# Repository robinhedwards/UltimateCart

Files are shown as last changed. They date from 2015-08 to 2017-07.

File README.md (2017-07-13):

Ultimate Cart
=============
The Ultimate Cart is an SD-card based multicart for the Atari 8-bit, which I've been developing for the last few months.
It allows you to browse the SD card on the atari and launch cartridge images from ROM and CAR files from the menu.
The PCB is designed to fit in a standard grey cartridge case (after a bit of modification with some clippers and a file).

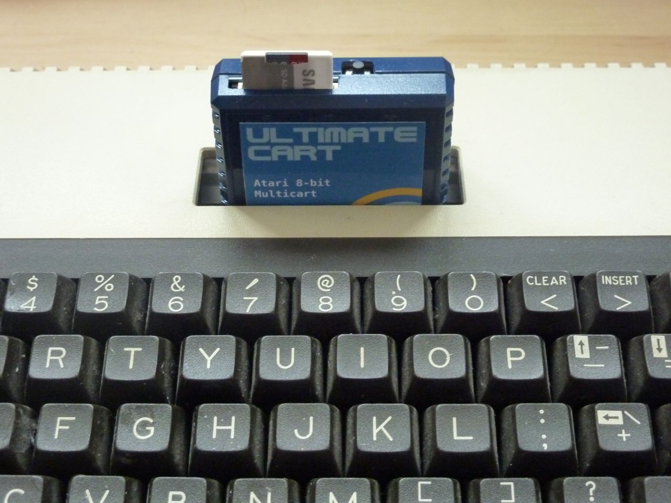
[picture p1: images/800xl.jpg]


It supports most ROMs up to 1 megabyte in size, including standard 8k and 16k cartridges, XEGS, AtariMax 1 & 8mbit ROMs,
SIC! Cart, Bounty Bob, OSS, SDX & Williams. ROM dumps can be easily converted into CAR format with my html/javascript
conversion utility, [RomToCar](http://htmlpreview.github.com/?https://github.com/robinhedwards/UltimateCart/master/RomToCar.html).

Update (Feb-2016)
-----------------
New firmware also allows XEX files (Atari executables) to be launched direct from the SD card.

PCB Images
----------
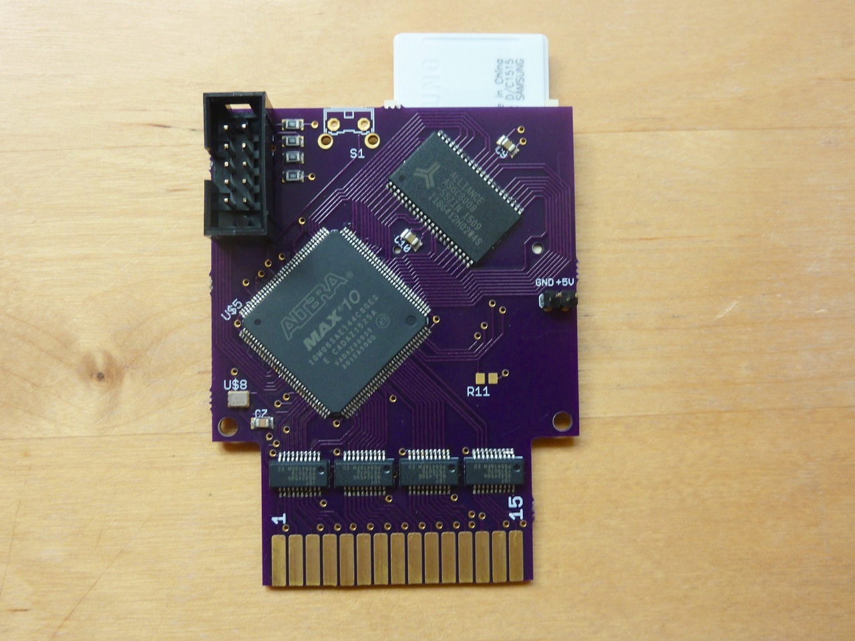
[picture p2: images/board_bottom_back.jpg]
Bottom/Back of PCB when inserted in Atari

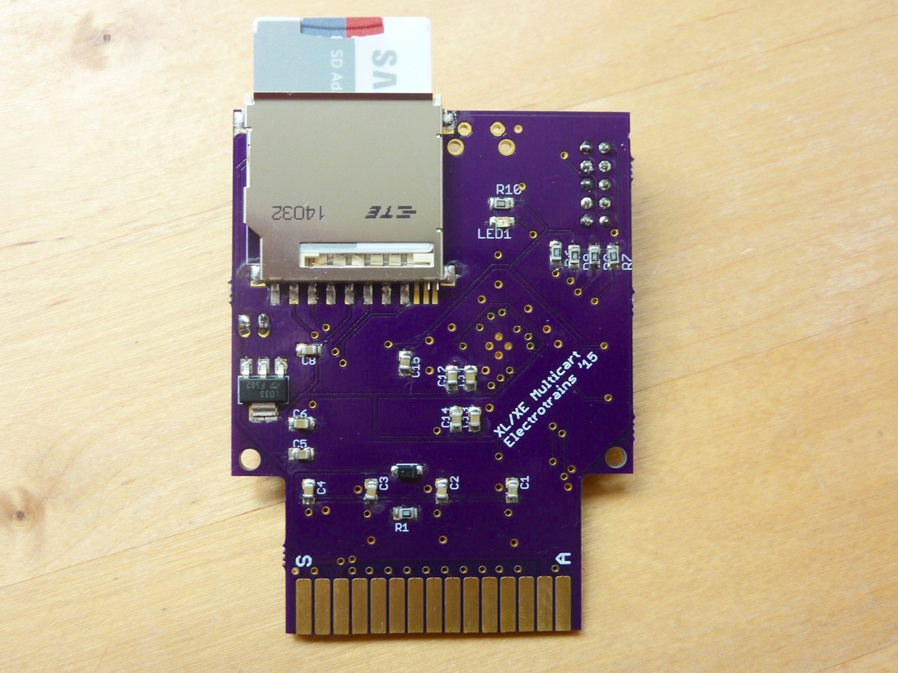
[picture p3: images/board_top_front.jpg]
Top/Front of PCB when inserted in Atari


Bill of Materials
-----------------

The FPGA originally used was an engineering sample (ES) variant of the chip. The production version of the FPGA is now available
and can be used instead. The programming files for the ES seem to work fine on the production chip.

```
1 x PCB (eagle .brd file can be uploaded to e.g. OSH park)
1 x Altera 10M08SAE144C8G or ES variant (Mouser part #989-10M08SAE144C8G/ES)
1 x Alliance Memory AS6C8008-55ZIN (Mouser part #913-AS6C8008-55ZIN)
4 x IDT QS3245QG (Mouser part #972-QS3245QG)
1 x 1N4148 Diode SOD-123 (e.g. RS Stock # 700-3671)
1 x Abracon ASE-50.000MHZ-ET (Farnell order code #2467898)
1 x LD1117S33TR (Farnell order code #1202826)
1 x TE Connectivity 2041021-3 or -4 (Farnell order code #2112526, Mouser part #571-2041021-1)
1 x Shrouded box header 2x5 (e.g. Hobbytronics.co.uk - BOXHEAD25, Farnell order code #2215304)
1 x Momentary tactile switch Right Angled PCB Mount (ebay)
3 x 10uF 0805 Capacitors (e.g. Farnell order code #2320856)
11 x 0.1uF 0805 Capacitors (e.g. Farnell order code #1759143)
1 x 0.01uF 0805 Capacitor (e.g. Farnell order code #1759246)
9 x 10k 0805 Resistor (e.g. Farnell order code #2447553)
1 x 0805 LED (e.g. Farnell order code #1581239)
1 x 200ohm 0805 Resistor (e.g. Farnell order code #2447602)
1 x Header male 2x1 0.1" pitch
1 x 47k 0805 Resistor (e.g. Farnell order code #2447664) [v3 Board only]
```

Assembly
--------

Although the schematic, board file and assembled images above are probably sufficient by themselves
for a determined person to complete the board, here is the method I'm using to assemble the boards.

You will need:
```
Solder paste (I used standard chipquik unleaded) syringe
Some way of reflowing the board (e.g. cheap toaster oven)
Solder paste stencil for the fpga side (optional, but recommended - see below)
Tweezers (or a better tool) for placing the components
Soldering iron
Flux and braid to fix any bridged pins (you may not need if you use a stencil)
USB Blaster to program the fpga
Blu-tac I find useful for keeping things steady
```

You can either apply solder paste by hand (using a syringe) or using a stencil. Having done it both ways,
I'd say the ten pounds I spent on a stencil was the best money I've ever spent! You can get a stencil made
cheaply from a variety of places. I'd recommend either oshstencils (USA) or smtstencil.co.uk (UK). The
paste layer was not correct on the original board, but was corrected in the revised version.

Apply the solder paste to the fpga side of the board, making sure you don't forget the ground pad. The
revised board removes R11 (a pullup resistor on the SD card line) which is not required (since SD cards
have an internal pull-up on CS).

Then populate the components, with reference to the marks on the board and the images above.
Bake the board in an over until the paste melts (you'll see it shine), leave it for about 30s-1min, then open
the oven door and let it cool.

Apply solder paste to the other side of the board (leaving the SD card which is hand soldered). There is
less need for a stencil for this side of the board, a syringe is fine. Populate (make sure you get the polarity
of the LED and diode correct) and bake again.

Before you do any hand soldering, check for bridged pins on the ICs. Some pins are bridged on the PCB - thats ok.
Any others, use braid, flux and soldering iron to remove.

Next you will need to hand solder the jtag box header (slot facing outwards), and 2x1 male header.

Now is a good time to check for shorts - (1) between the +5V and GND pins of the male header, (2) between +3.3v
and GND on the regulator, and (3) between VCC and GND on the IDT quickswitches. If you find a short then STOP
and fix it. There will be a bridge somewhere. Refer to the eagle files to help identify the location.

Once that's done, you should be able to power up the board, plug in a USB blaster and program the chip from
Quartus (use the pof file - this permanently programs the chip). If successful you should see the LED on the
board blinking.

Finally, hand solder the SD card slot and reset button to the board. You're done!

Erratum (20-Oct-15)
-------
Someone who has built this project got in touch to report that some SD cards fail to be recognised.
It appears that a 10k-100k pullup is required on the SD card DO (pin 7), or some cards will fail to initialise.
I haven't come across this in the 10 different SD cards I've tested, but if you do have problems then you can fix
it by adding a 47k pull-up resistor as shown in the photo below.

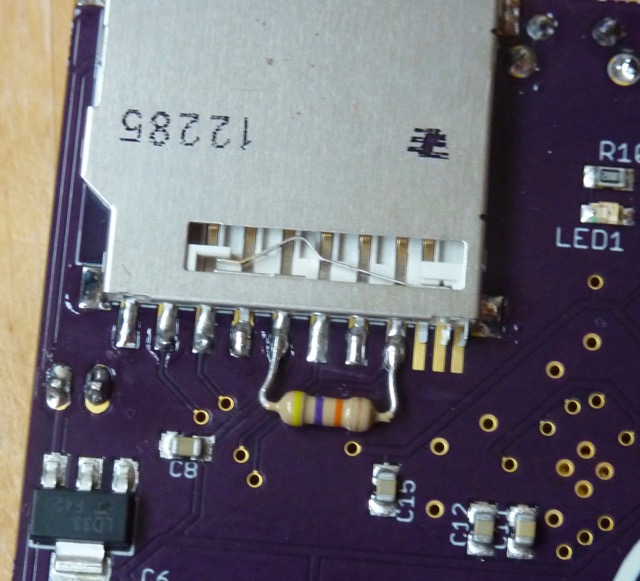
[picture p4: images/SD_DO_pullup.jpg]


Note (1-Mar-16) - I have now uploaded a revised version of the board (v3) which adds this resistor to the PCB (labelled R11).

3d Printed Cartridge Shell (13-Jul-17)
-------
I have added STL files (and the source files) so you can use a 3d printer to make a nice cartridge shell for your PCB.
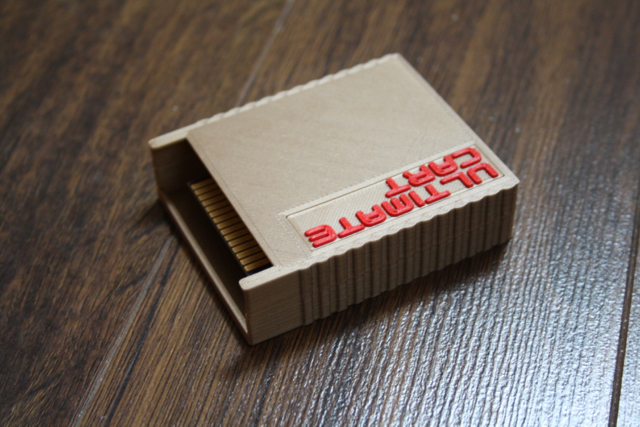
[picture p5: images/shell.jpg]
3d printed shell

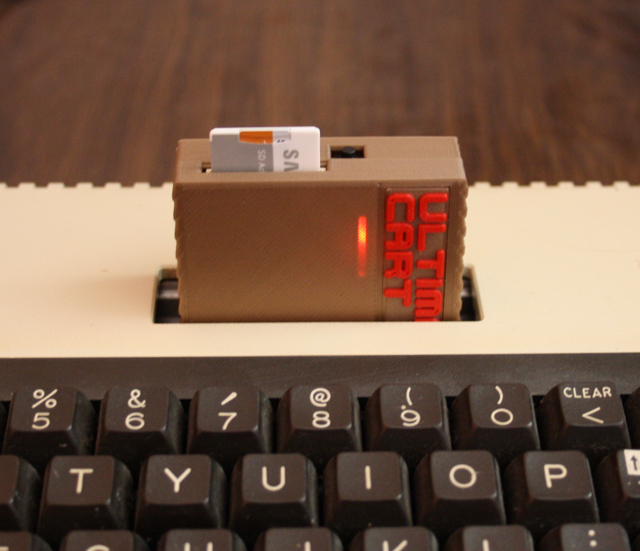
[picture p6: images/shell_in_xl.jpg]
3d printed shell when inserted in Atari


Credits
-------
* Design, PCB & FPGA firmware by Robin Edwards (electrotrains at atariage)
* Atari boot menu & XEX loader by Jonathan Halliday (flashjazzcat at atariage)
* Debugging - Matthias Reichl (HiassofT at atariage)
* Help, suggestions and FAT32 LFN code from Mark Watson (foft at atariage)

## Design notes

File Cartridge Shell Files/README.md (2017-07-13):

STL files for 3d printing a shell for the Ultimate Cart.
(License Creative Commons Attribution Share Alike 4.0)

Notes

The overall shape and dimensions were matched to an XL-era Atari Cartridge.

I sliced with Cura and printed on a Wanhao Duplicator i3 v2.1

Front and back are optimised for printing with a 0.3mm layer height.
The front requires support (i.e. scaffolding) under the reccess for the logo insert.

The logo was designed for a 0.2mm layer height, with a filament change after the third layer.

The OpenSCAD source files are supplied, should you want to tweak the design. Its probably not a good example of how to use OpenSCAD - this was my first attempt to use the software.

Requires 2 x M3 14mm screw (or slightly longer)

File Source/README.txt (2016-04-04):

The Quartus project needs Quartus II 15.1 or above.

Some notes
==========
You should be able to just compile to product a valid sof file.
To generate a pof from the sof file, select File/Convert Programming Files, then Mode: Internal Configuration.

The nios cpu build files are in the host directory, but can be regenerated from the host.qsys project.

The boot_rom.hex file can be updated with a new Atari 8k boot ROM file (see Source/AtariBootROM).
Do Processing/Update Memory Initialization File then Re-assemble after doing this.

To change the fpga Nios firmware, use Nios II software build tools for Eclipse. Both sdcard and sdcard_bsp projects need to be added to the workspace.
Make Targets/Build/mem_init_generate will generate the firmware hex file.
Then do Processing/Update Memory Initialization File and Re-assemble after doing this.

You can also debug the firmware in Eclipse with using the JTAG UART. Run as/Nios II Hardware and the console will display debug output.

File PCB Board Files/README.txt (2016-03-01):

Eagle files for the PCB.

v2 removes an un-needed pull-up resistor on the SD card CS line.
It also includes fixes to the paste layer so you can order a stencil from the board file.
Finally, it adds a funky logo to the top of the board to match the label.

v3 adds a 47k pull-up resistor (marked R11) to SD card as discussed in the erratum on the main page. R11 is on the SD card side of the board, near the SD card slot itself.

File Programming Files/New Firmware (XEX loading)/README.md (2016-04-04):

The new Firmware with XEX loading and better boot menu written by Jonathan Halliday (adds joystick control).

The programming files were generated from Quartus 15.1. Use the variant that matches the chip on your board.

The source code is for this firmware.

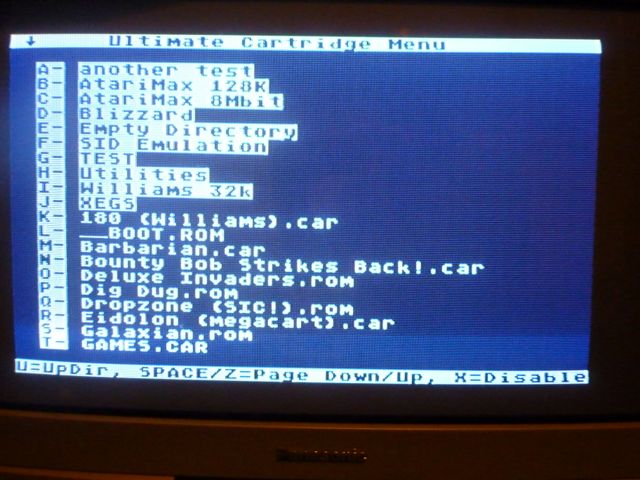
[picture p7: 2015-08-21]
images/menu.jpg

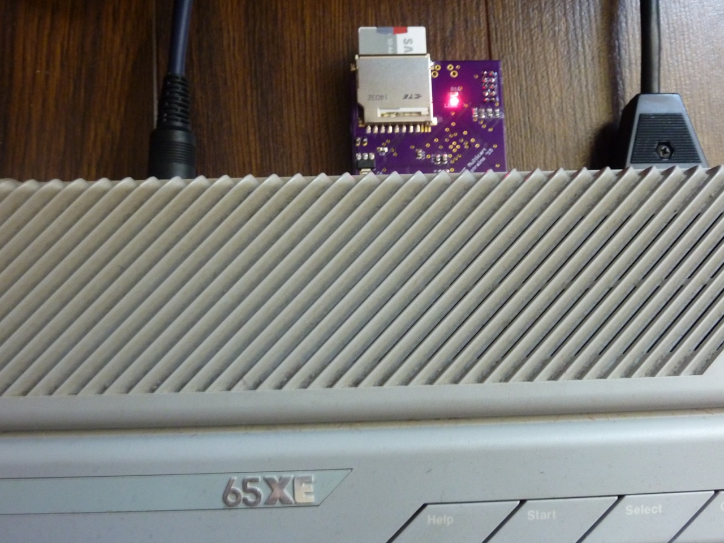
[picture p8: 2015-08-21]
images/uncased_65xe.jpg

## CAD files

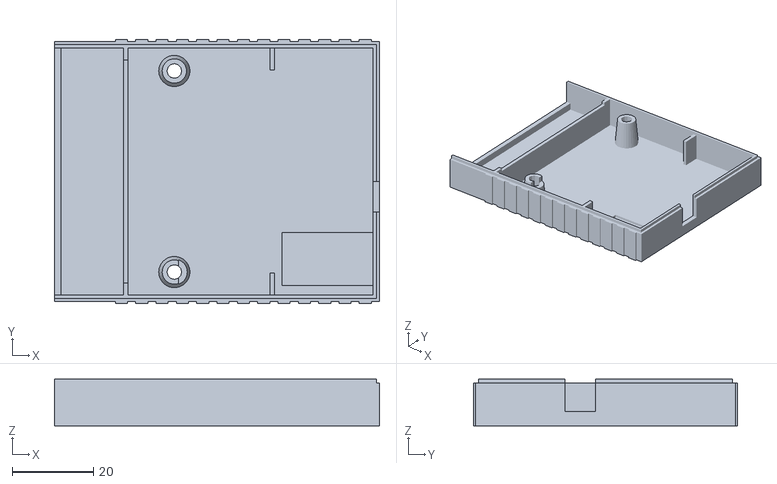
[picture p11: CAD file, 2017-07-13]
Cartridge Shell Files/ultimate_back.stl
80.0 x 65.0 x 11.5

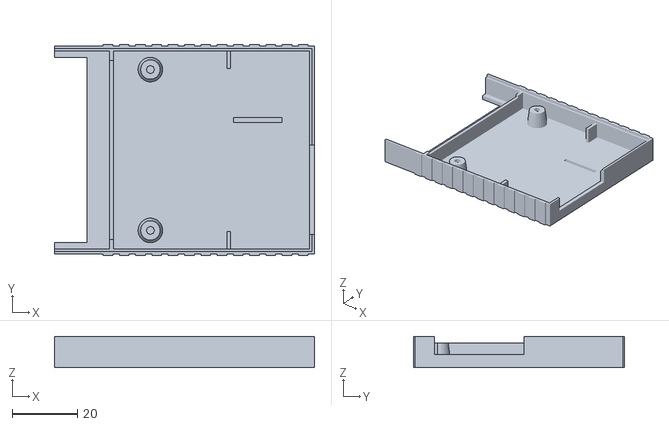
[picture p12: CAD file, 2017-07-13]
Cartridge Shell Files/ultimate_front.stl
80.0 x 65.0 x 9.60

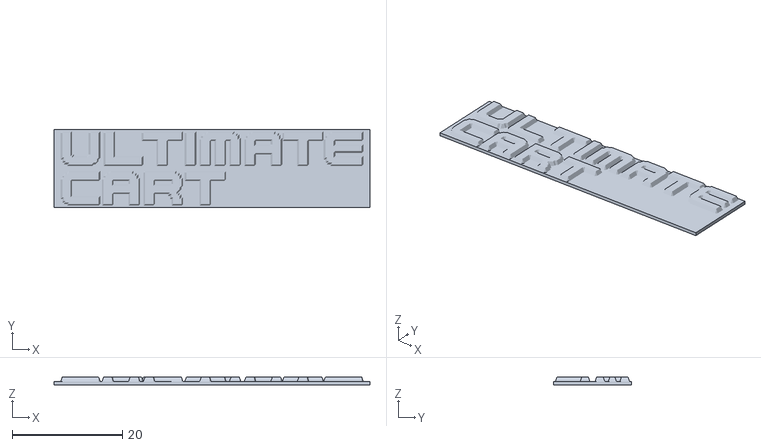
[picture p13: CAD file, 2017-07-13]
Cartridge Shell Files/ultimate_logo.stl
57.3 x 14.1 x 1.40

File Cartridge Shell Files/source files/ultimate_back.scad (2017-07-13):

/* Ultimate Cart shell
   (c) R.Edwards 2017
*/

ridge_width = 0.5;
cart_length=80;
cart_width=65 - (ridge_width*2);
cart_height=11.5;
screw_sep = 49.5;
front_thickness = 1.6;
sides_thickness = 1.6 - 0.05;
support_thickness = 1.2 - 0.05;
support_height = 10.5;
rim_height=1;

difference() {
    union() {
        difference() {
            // main shell
            union() {
                cube([cart_length, cart_width, cart_height-rim_height]);
                // rim
                translate([0, sides_thickness/2, cart_height-rim_height])
                    cube([cart_length-sides_thickness/2, sides_thickness/2, rim_height]);
                translate([0, cart_width-sides_thickness, cart_height-rim_height])
                    cube([cart_length-sides_thickness/2, sides_thickness/2, rim_height]);
                translate([cart_length-sides_thickness, sides_thickness/2, cart_height-rim_height])
                    cube([sides_thickness/2, cart_width-sides_thickness, rim_height]);
            }
            // make hollow
            translate([0, sides_thickness, front_thickness])
                cube([cart_length-sides_thickness,
                    cart_width-sides_thickness*2,
                    cart_height-front_thickness]);
            // cutout reset button slot
            translate([cart_length-sides_thickness, 22, cart_height-8])
                cube([sides_thickness, 7.5, 8]);
            // cutout programming header
            translate([56, 4, front_thickness/2])
                cube([22.5, 13, front_thickness]);
        }    
        // end
        cube([sides_thickness, cart_width, 4]);
        // pcb supports
        difference() {
            translate([17, sides_thickness, 0])
                cube([support_thickness, cart_width-sides_thickness*2, cart_height]);
            translate([17, (cart_width-55)/2, support_height])
                cube([support_thickness, 55, cart_height-support_height]);
        }
        translate([53, 0, 0])
            cube([support_thickness, 7, support_height]);
        translate([53, cart_width-7, 0])
            cube([support_thickness, 7, support_height]);
        // screw holes
        difference() {
            translate([29.5, (cart_width-screw_sep)/2, 0])
                difference() {
                    cylinder(h = support_height, r1 = 4, r2 = 3,  $fs = 1);
                    cylinder(h = support_height, r1 = 1.8, r2 = 1.8,  $fs = 1);
                }
            translate([29.5+1, (cart_width-screw_sep)/2-5, support_height-2])
                cube([10, 10, 2]);
        }
        translate([29.5, cart_width-(cart_width-screw_sep)/2, 0])
            difference() {
                cylinder(h = support_height, r1 = 4, r2 = 3,  $fs = 1);
                cylinder(h = support_height, r1 = 1.8, r2 = 1.8,  $fs = 1);
            }
        // ridges
        for (i = [15: 5: cart_length-5])
            union() {
                translate([i, -ridge_width, 0])
                    cube([3, ridge_width, cart_height-rim_height]);
                translate([i, cart_width, 0])
                    cube([3, ridge_width, cart_height-rim_height]);
            }
    }
    // screw head
    translate([29.5, (cart_width-screw_sep)/2, 0])
        cylinder(h = 0.6, r1 = 3.5, r2 = 3.5,  $fs = 1);
    translate([29.5, (cart_width-screw_sep)/2, 0.6])
        cylinder(h = front_thickness-0.6, r1 = 3.5, r2 = 1.8,  $fs = 1);

    translate([29.5, cart_width-(cart_width-screw_sep)/2, 0])
        cylinder(h = 0.6, r1 = 3.5, r2 = 3.5,  $fs = 1);
    translate([29.5, cart_width-(cart_width-screw_sep)/2, 0.6])
        cylinder(h = front_thickness-0.6, r1 = 3.5, r2 = 1.8,  $fs = 1);
}

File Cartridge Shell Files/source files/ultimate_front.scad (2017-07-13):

/* Ultimate Cart shell
   (c) R.Edwards 2017
*/

ridge_width = 0.5;
cart_length=80;
cart_width=65 - (ridge_width*2);
cart_height=9.6;
screw_sep = 49.5;
front_thickness = 1.6;
sides_thickness = 1.6 - 0.05;
support_thickness = 1.2 - 0.05;
support_height = 7.6;
rim_height = 1;
logo_width = 14.5;
logo_height = 58;

difference() {
    union() {
        difference() {
            // main shell
            cube([cart_length, cart_width, cart_height]);
            // rims
            translate([0, sides_thickness/2, cart_height-rim_height])
                cube([cart_length-sides_thickness/2,
                    cart_width-sides_thickness, rim_height]);
            // make hollow
            translate([0, sides_thickness, front_thickness])
                cube([cart_length-sides_thickness,
                    cart_width-sides_thickness*2,
                    cart_height-front_thickness]);
            // cutout sd card slot
            translate([cart_length-sides_thickness, 6, cart_height-5.5])
                cube([sides_thickness, 27.5, 5.5]);
            // cutout cart port
            translate([0, (cart_width-57)/2, 0])
                cube([10, 57, cart_height]);
            // cutout led shine through
            translate([55, 40.5, 0.3])
                cube([15, 1.5, front_thickness-0.3]);
        }    
        // pcb supports
        difference() {
            translate([17, 0, 0])
                cube([support_thickness, cart_width, cart_height-rim_height]);
            translate([17, (cart_width-55)/2, support_height])
                cube([support_thickness, 55, cart_height-support_height]);
        }
        translate([53, 0, 0])
            cube([support_thickness, 7, support_height]);
        translate([53, cart_width-7, 0])
            cube([support_thickness, 7, support_height]);
        // screw holes
        translate([29.5, (cart_width-screw_sep)/2, 0])
            difference() {
                cylinder(h = support_height, r1 = 4, r2 = 3,  $fs = 1);
                cylinder(h = support_height, r1 = 1.25, r2 = 1.25,  $fs = 1);
            }
        translate([29.5, cart_width-(cart_width-screw_sep)/2, 0])
            difference() {
                cylinder(h = support_height, r1 = 4, r2 = 3,  $fs = 1);
                cylinder(h = support_height, r1 = 1.25, r2 = 1.25,  $fs = 1);
            }
        // ridges
        for (i = [15: 5: cart_length-5])
            union() {
                translate([i, -ridge_width, 0])
                    cube([3, ridge_width, cart_height]);
                translate([i, cart_width, 0])
                    cube([3, ridge_width, cart_height]);
            }
    }
    // logo space
    translate([cart_length-logo_height-2, cart_width-logo_width-3.5, 0])
        cube([logo_height, logo_width, 1]);
}

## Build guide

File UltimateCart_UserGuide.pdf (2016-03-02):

## Ultimate Cartridge for Atari 8-bit Computers

### Website

The Ultimate Cart is a multi-cart for Atari 400/800/XL/XE computers. It is open-source hardware and software. The project website is: https://github.com/robinhedwards/UltimateCart

### Basic Usage

The Ultimate Cartridge can be used uncased in an XE system.

Mounting inside a cartridge case is recommended for XL computers since the flaps on the slot may damage the bare PCB.

The SD card slot side should be facing upward (or forwards) in the computer, with the chip side downwards (or backwards).

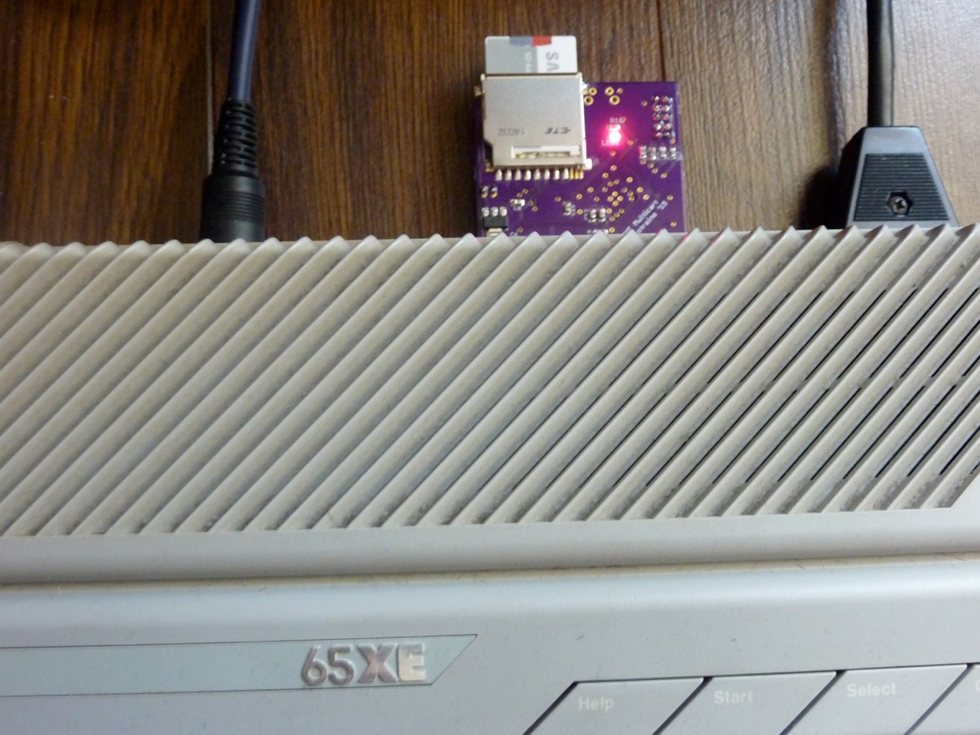
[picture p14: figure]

Insert an SD card (either full size, or MicroSD in an adapter) into the slot. The card does not require any special preparation, since the Ultimate cartridge can read FAT (including FAT32) file systems. Long file names are supported.

When the Atari is powered on, a list of any ROM & CAR files and directories on the SD card should be shown on the Atari’s screen. Keyboard commands are shown at the bottom of the screen. A newer version of the firmware also supports XEX files – this may be installed on your cartridge.

It is best to organize your files in directories since the cartridge will load and sort the files in the directory before display. If you have to many files in any one directory, this may cause a noticeable pause before display.

You can disable the cartridge (using the X key) if you want to boot normally (e.g. to disk) and leave the cartridge plugged in (to avoid wear and tear).

### SD Cards

Higher speed SD cards are recommended. SDHC (High capacity) cards are supported. On a high-speed card, a 1 megabyte ROM file (e.g. AtariMax) takes about 3 seconds to be loaded into the cartridge when selected. Slower cards may take longer.

### Status LED

LED | Meaning
Blinking | The cartridge menu screen is active
On | Selected cartridge is enabled for access (RD4 or RD5 active)
Off | Selected cartridge is disabled (RD4 and RD5 inactive)

### Reset Button

Press the reset button (next to the SD card slot) to reset the cartridge firmware. This will generally cause the Atari to crash, and the reset button on the Atari can then be pressed to return to the cartridge menu.

### Supported Cartridge Types (CAR files)

Description | CAR Type(s)
Standard Atari 8k | 1
Standard Atari 16k | 2
Atari XEGS 32-1024k | 12-14, 23-25
AtariMax 1mbit (128k) | 41
AtariMax 8mbit (1024k) | 42
Switchable XEGS 32-1024k | 33-38
Megacart 16-1024k | 26-32
Bounty Bob | 18
Williams 32k, 64k | 8, 22
OSS 8k | 44
OSS 16k (034M) | 3
OSS 16k (043M) | 45
OSS 16k (type B) | 15
SIC!Cart (128k, 256k, 512k) | 54-56
SDX 64k | 11
Diamond 64k | 10
Express 64k | 9
SDX 128k | 43
Blizzard 16k | 40

### Converting to CAR format

Utilities are available to convert ROM/BIN files into the CAR file format. The ROM2CAR utility available on the project website provides an easy drag and drop interface to do this.

With the most common 8k and 16k Atari ROMs, there is no need to convert these first to CAR format since these cartridge types will simply be assumed from the size of the ROM file (see below).

### ROM Files

Plain ROM files are supported, but since these files are raw cartridge dumps, the Ultimate Cart will decide what type of cartridge they come from based on the file size only. The table below shows what types will be used.

ROM File Size | Cartridge Type
8k | Standard Atari 8k
16k | Standard Atari 16k
32k | Atari XEGS 32k
64k | Atari XEGS 64k
128k | Atari XEGS 128k
256k | SIC!Cart
512k | SIC!Cart
1024k | AtariMax 8mbit

### XEX Files

The latest version of the firmware adds a new menu, with joystick control. It also supports loading XEX files (in addition to cartridge files). Note that the XEX loader is copied to location $700 in the Atari’s RAM. This should be compatible with most software in XEX form.

### Problem Files

You may come across files with a .BIN extension. These are often just .ROM files and can be renamed.

You may also find ROM files where the Ultimate Cart menu gives the error “Bad ROM/CAR file”. This happens when the ROM file is not an exact multiple of 1,024 bytes. In this case, the ROM dump may have already been converted to a CAR file (with a 16 byte header) but has been wrongly named. In this case you can simply rename the file from .ROM to .CAR.

### Alternative Menu

If a file named _BOOT.ROM (8k) is present in the root directory of the SD card, the cartridge will attempt to overwrite the in-built boot ROM with this file before the Atari starts accessing the ROM. This allows the menu to be replaced with an alternative version, but successful operation may require a fast SD card. Delete the file to revert to the built-in menu.

Source code for the built-in menu is available on the project website.

Note that setting the hidden or system flag on _BOOT.ROM (using a PC) will prevent this file being displayed on the menu.

### Cartridge Cases

The Ultimate Cart PCB is designed to fit in a modified Atari grey (XL-era) cartridge shell. You will need a heavy-duty file and some clippers (e.g. wire clippers). This is only intended to be a rough guide.

First separate the two sides of the shell, trying not to break any of the tabs that hold the two parts of the shell together. Remove the original PCB and any glue blobs.

From the front (i.e. facing forwards when inserted) part of the shell you will need to remove the plastic centre “post” at its base, since there is no hole in the Ultimate Cart PCB. You will also need to remove the central “clip” at the top of the front shell.

You should then be able to roughly place the Ultimate Cart PCB (chip side up) in the top of the shell (like the PCB you removed). It won’t sit correctly (yet).

At this point it will be clear that you will need to remove 2-3mm height of the side extensions on the top and (partially on the) bottom shell. It should also be clear where slots need to be filed in the front and back of the shell to accommodate the SD card and button.

### Upgrading the Firmware

Should new firmware be available, a USB Blaster (or clone) can be used to upgrade your cartridge. A JTAG socket is present on the FPGA side of the board. Connect this to the USB Blaster and power the board. A POF file can then be programmed to the chip using the Altera Quartus Programmer (free download).

To power the board, either supply 5V using the two pin header provided. Alternatively, the board can be powered during the firmware update through the cartridge slot of the Atari.

### Board Assembly Information

If you purchased an assembled cartridge from the author, the cartridge has been assembled one of two ways:

Boards purchased before Sept 2015

Assembled using two types of lead-free solder paste. The lower side (with two large chips) uses Sn42Bi58 paste (melting point 130 degrees C). The upper side (with the SD card slot) uses Sn96.5Ag3Cu0.5 paste (melting point 230 degrees), with the exception of the SD card slot itself, which has been soldered with Sn42Bi58. In case of repair, avoid leaded solder since it will lead to brittle and poor joints if mixed with Sn42Bi58.

Boards purchased on or after Sept 2015

Assembled using SN96.5Ag3Cu0.5 paste on both sides (melting point 230 degrees).

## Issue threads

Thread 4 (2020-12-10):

Memory Short

Kalidomra, 2020-12-10:
I have tried to build this twice. Each time there seems to be a dead short to the memory after programming. Everything is fine, I program the chip and the memory chips gets too hot to touch. What am I doing wrong?

pazuzu72, 2020-12-20:
> I have tried to build this twice. Each time there seems to be a dead short to the memory after programming. Everything is fine, I program the chip and the memory chips gets too hot to touch. What am I doing wrong?

Can you post a photo o pcb populated?

Kalidomra, 2020-12-20:
Sure, here it is.
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

pazuzu72, 2020-12-21:
The photo is not very clear. Are you sure there is no solder bridge?

Kalidomra, 2020-12-29:
Here is what I have done:

1st attempt:
- Soldered all of the parts, inspected for solder bridges. Powered the board, no issues. Minimal power draw.
- Programmed the Altera.
- After programming, upon power up the board was drawing too much power and memory was hot to the touch.
- Powered down.
- Removed the memory, installed on a blank board.
- Powered the new blank board, memory was still drawing too much power and getting hot.
- Reinspected the original board via microscope, no solder bridges.
- Ordered new memory chip, installed, same result.
- Gave up

2nd attempt:
- Ordered all new parts.
- Install everything except U1-4, SD card socket and switch.
- Triple checked every connection.
- Same result as first attempt.

pazuzu72, 2020-12-29:
I have no idea !! I've done more than 130, this has never happened to me. I program them directly powered by an atari computer, not via the external 2 pin header. Nothing else comes to mind.

jhusak, 2020-12-30:
I think the issue may be in unstable inputs when no level shifters installed. I would solder them in and then test.
This is non-standard behavior when mounting only some parts, not all, as other people.

Kalidomra, 2020-12-30:
In my first attempt I had all of the components installed proper to programming.  There may be an issue with the gerber files I generated. Would it be possible to post the gerbers for the successful builds?

pazuzu72, 2020-12-31:
[Ulimate_2020-12-31.zip](https://github.com/robinhedwards/UltimateCart/files/5757515/Ulimate_2020-12-31.zip)
Sure!

pazuzu72, 2020-12-31:
[Ultimate_Cart_gerber.zip](https://github.com/robinhedwards/UltimateCart/files/5757521/Ultimate_Cart_gerber.zip)
Sure!

Kalidomra, 2020-12-31:
Is it possible that powering the board without being hooked to the logic and pull up or pull downs for the Atari is causing the Altera to get in a state that drives the WE High and also tries to drive the Data pins?

mulcmu, 2021-01-01:
I built 3 and programmed them using the external +5V power input headers without being installed in an Atari.

pazuzu72, 2021-01-01:
> Is it possible that powering the board without being hooked to the logic and pull up or pull downs of the Atari is causing the Altera to get in a state that drives the WE High and also tries to drive the Data pins?

I don't think that's the problem!

Kalidomra, 2021-01-02:
I have been doing a little troubleshooting today. I  setup the scope on the 5v rail and noticed a 13v spike for 6ms on switching on the power supply. Would that be enough to fry the sram? I have also checked the entire board, there are no shorts, it all connected correctly.

jhusak, 2021-01-03:
Well, I would throw away such a "stabilized" power supply. Yes, it would kill your chips. 6 ms is a long time.

Kalidomra, 2021-01-03:
Yup, cheap POS. New one on order. I will also get some new  SRAM and try again. I'm sure that was the issue. Thanks for all the help.

pazuzu72, 2021-01-03:
You can power it inserted in atari cartridge port for programming!!! I always do in that way.

Closed 2021-01-21.

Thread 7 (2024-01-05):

gerber files?

vwbug2007, 2024-01-05:
where's the Gerber files? those are not compatible with jlcpcb website

vwbug2007, 2024-01-05:
also kicad export to gerber fails drc

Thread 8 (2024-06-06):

Bug in the SIC! cart support

woj76, 2024-06-06:
It seems that both "left" and "right" SIC! cart banks are always switched on regardless of the control register configuration resulting in the whole $8000-$BFFF memory range always being mapped when the cart is active. At least this is the best diagnosis I can do without the emulator, and this behaviour breaks my particular SIC! image cart that I developed. The same cart image works fine everywhere else (AVG, SIDE3, Altirra).

woj76, 2025-01-10:
I investigated this a bit more, and so far I can conclude that the problem I saw is **not** related to the SIC! banking mechanism implementation in UC, so my first claim does not hold. So even though I do get some weird behavior suggesting some problems with device memory mapping on my Atari, it is related to something else (someone suggested cart RAM issues / bad soldering).

robinhedwards, 2025-01-10:
thanks for the update. Closing this issue for now.

woj76, 2025-03-20:
I would like to re-open this, I finally identified the problem, it is in the VHDL, I fixed it a local copy and tested. The issue is that SIC! carts are by default initialized to low bank off and high bank on, UC initialized both banks to on. The line 275 in atari_rom.vhd:

low_bank_enabled <= '1';

should be simply removed.

Closed 2025-01-10.

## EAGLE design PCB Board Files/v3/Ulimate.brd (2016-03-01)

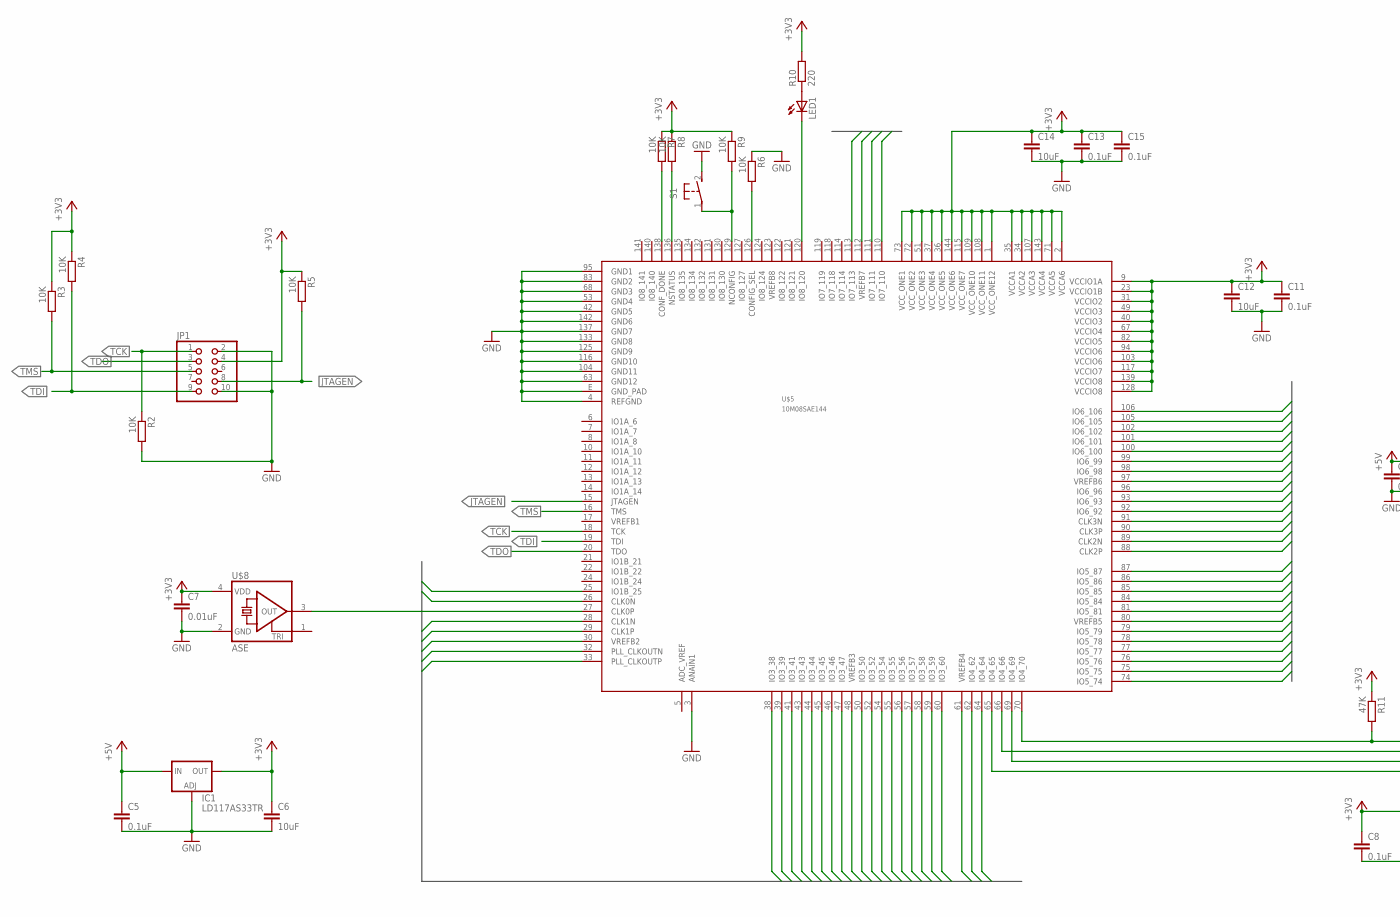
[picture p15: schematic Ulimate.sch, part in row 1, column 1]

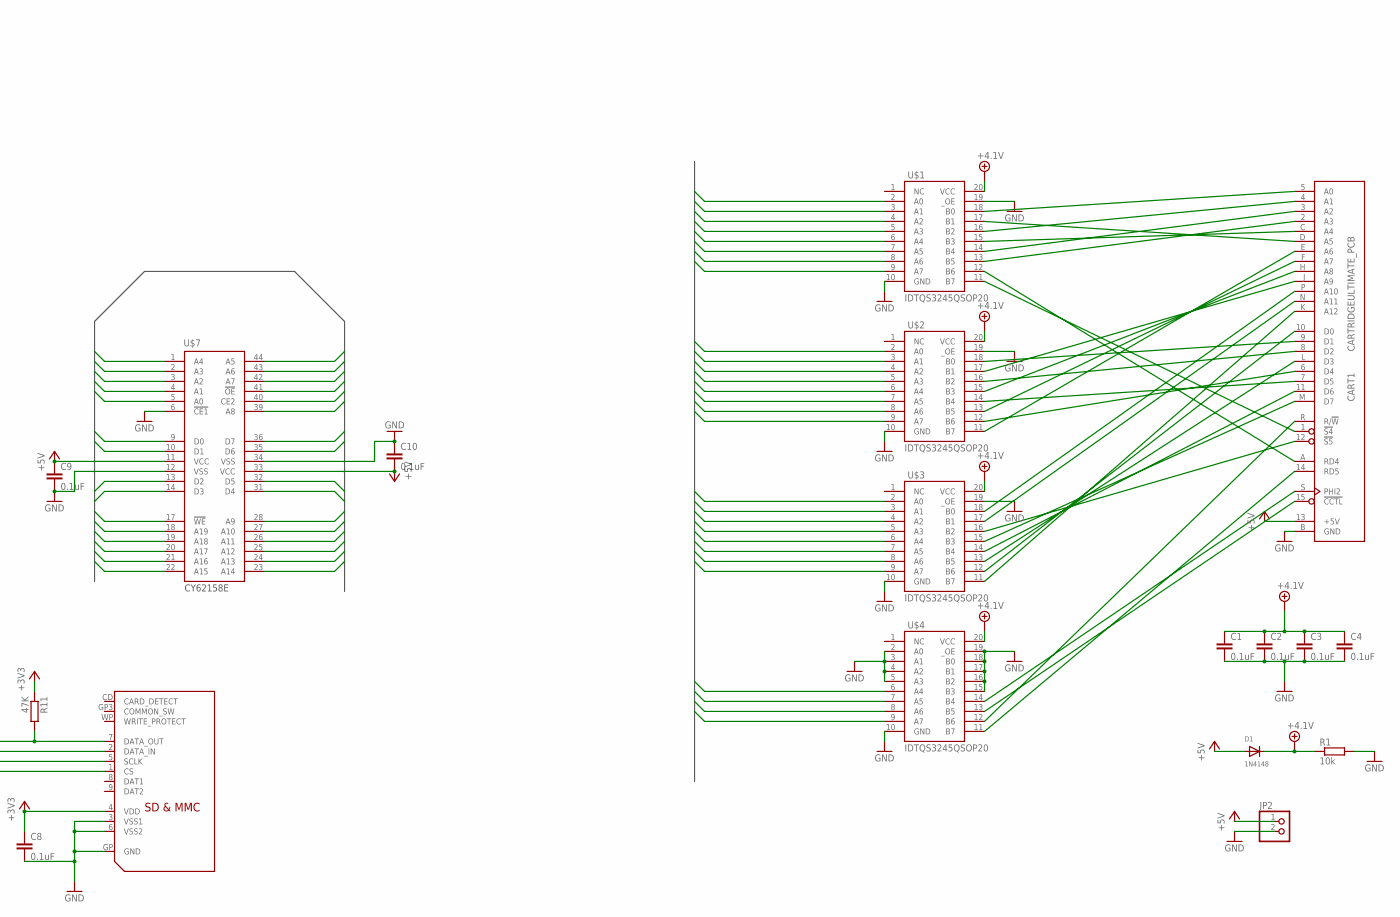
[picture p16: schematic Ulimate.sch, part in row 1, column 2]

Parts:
C1, C2, C3, C4, C5, C8, C9, C10, C11, C13, C15: 0.1uF; C0805K
C6, C12, C14: 10uF; C0805K
C7: 0.01uF; C0805K
CART1: CARTRIDGEULTIMATE_PCB; CART_ULTIMATE
D1: 1N4148; SOD-123FL
IC1: LD117AS33TR; SOT223
JP1: PINHD-2X5; 2X05
JP2: PINHD-1X2; 1X02
LED1: LEDSML0805; SML0805
R1: 10k; R0805
R2, R3, R4, R5, R6, R7, R8, R9: 10K; R0805
R10: 220; R0805
R11: 47K; R0805
S1: 31-XXSKINNY; B3F-31XX-SKINNIER
U$1, U$2, U$3, U$4: IDTQS3245QSOP20; QSOP20
U$5: 10M08SAE144; EQFP144
U$6: SDMMC06132; 06132
U$7: CY62158E; TSOP44-II
U$8: ASE

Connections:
!OE: U$5.106 (IO6_106), U$7.41 (!OE)
!WE: U$5.89 (CLK2N), U$7.17 (!WE)
+3V3: C6.1, C7.1, C8.1, C11.1, C12.1, C13.1, C14.1, C15.1, IC1.4 (OUT), JP1.4, R3.1, R4.1, R5.1, R7.1, R8.1, R9.1, R10.2, R11.1, U$5.1 (VCC_ONE12), U$5.2 (VCCA6), U$5.9 (VCCIO1A), U$5.23 (VCCIO1B), U$5.31 (VCCIO2), U$5.34 (VCCA2), U$5.35 (VCCA1), U$5.36 (VCC_ONE5), U$5.37 (VCC_ONE4), U$5.40 (VCCIO3), U$5.49 (VCCIO3), U$5.51 (VCC_ONE3), U$5.67 (VCCIO4), U$5.71 (VCCA5), U$5.72 (VCC_ONE2), U$5.73 (VCC_ONE1), U$5.82 (VCCIO5), U$5.94 (VCCIO6), U$5.103 (VCCIO6), U$5.107 (VCCA3), U$5.108 (VCC_ONE11), U$5.109 (VCC_ONE10), U$5.115 (VCC_ONE7), U$5.117 (VCCIO7), U$5.128 (VCCIO8), U$5.139 (VCCIO8), U$5.143 (VCCA4), U$5.144 (VCC_ONE6), U$6.4 (VDD), U$8.4 (VDD)
+4.1V: C1.1, C2.1, C3.1, C4.1, D1.C, R1.1, U$1.20 (VCC), U$2.20 (VCC), U$3.20 (VCC), U$4.20 (VCC)
+5V: C5.1, C9.1, C10.2, CART1.13 (+5V), D1.A, IC1.3 (IN), JP2.1, U$7.11 (VCC), U$7.33 (VCC)
A0: U$5.96 (IO6_96), U$7.5 (A0)
A1: U$5.97 (VREFB6), U$7.4 (A1)
A2: U$5.98 (IO6_98), U$7.3 (A2)
A3: U$5.99 (IO6_99), U$7.2 (A3)
A4: U$5.100 (IO6_100), U$7.1 (A4)
A5: U$5.105 (IO6_105), U$7.44 (A5)
A6: U$5.102 (IO6_102), U$7.43 (A6)
A7: U$5.101 (IO6_101), U$7.42 (A7)
A8: U$5.111 (IO7_111), U$7.39 (A8)
A9: U$5.76 (IO5_76), U$7.28 (A9)
A10: U$5.77 (IO5_77), U$7.27 (A10)
A11: U$5.78 (IO5_78), U$7.26 (A11)
A12: U$5.79 (IO5_79), U$7.25 (A12)
A13: U$5.80 (VREFB5), U$7.24 (A13)
A14: U$5.81 (IO5_81), U$7.23 (A14)
A15: U$5.84 (IO5_84), U$7.22 (A15)
A16: U$5.85 (IO5_85), U$7.21 (A16)
A17: U$5.86 (IO5_86), U$7.20 (A17)
A18: U$5.87 (IO5_87), U$7.19 (A18)
A19: U$5.88 (CLK2P), U$7.18 (A19)
CART_A0: U$1.2 (A0), U$5.39 (IO3_39)
CART_A1: U$1.4 (A2), U$5.33 (PLL_CLKOUTP)
CART_A2: U$1.6 (A4), U$5.30 (VREFB2)
CART_A3: U$1.7 (A5), U$5.29 (CLK1P)
CART_A4: U$1.5 (A3), U$5.32 (PLL_CLKOUTN)
CART_A5: U$1.3 (A1), U$5.38 (IO3_38)
CART_A6: U$2.9 (A7), U$5.41 (IO3_41)
CART_A7: U$2.7 (A5), U$5.44 (IO3_44)
CART_A8: U$2.5 (A3), U$5.46 (IO3_46)
CART_A9: U$2.3 (A1), U$5.48 (VREFB3)
CART_A10: U$3.2 (A0), U$5.60 (IO3_60)
CART_A11: U$3.3 (A1), U$5.59 (IO3_59)
CART_A12: U$3.9 (A7), U$5.52 (IO3_52)
CART_CTL: U$4.7 (A5), U$5.64 (IO4_64)
CART_D0: U$3.8 (A6), U$5.54 (IO3_54)
CART_D1: U$2.2 (A0), U$5.50 (IO3_50)
CART_D2: U$2.4 (A2), U$5.47 (IO3_47)
CART_D3: U$3.7 (A5), U$5.55 (IO3_55)
CART_D4: U$2.8 (A6), U$5.43 (IO3_43)
CART_D5: U$2.6 (A4), U$5.45 (IO3_45)
CART_D6: U$3.6 (A4), U$5.56 (IO3_56)
CART_D7: U$3.5 (A3), U$5.57 (IO3_57)
CART_PHI: U$4.6 (A4), U$5.26 (CLK0N)
CART_RD4: U$1.8 (A6), U$5.25 (IO1B_25)
CART_RD5: U$4.9 (A7), U$5.61 (VREFB4)
CART_RW: U$4.8 (A6), U$5.62 (IO4_62)
CART_S4: U$1.9 (A7), U$5.28 (CLK1N)
CART_S5: U$3.4 (A2), U$5.58 (IO3_58)
CE: U$5.110 (IO7_110), U$7.40 (CE2)
D0: U$5.93 (IO6_93), U$7.9 (D0)
D1: U$5.92 (IO6_92), U$7.10 (D1)
D2: U$5.91 (CLK3N), U$7.13 (D2)
D3: U$5.90 (CLK3P), U$7.14 (D3)
D4: U$5.75 (IO5_75), U$7.31 (D4)
D5: U$5.74 (IO5_74), U$7.32 (D5)
D6: U$5.113 (IO7_113), U$7.35 (D6)
D7: U$5.112 (VREFB7), U$7.36 (D7)
GND: C1.2, C2.2, C3.2, C4.2, C5.2, C6.2, C7.2, C8.2, C9.2, C10.1, C11.2, C12.2, C13.2, C14.2, C15.2, CART1.B (GND), IC1.1 (ADJ), JP1.2, JP1.10, JP2.2, R1.2, R2.2, R6.1, S1.2 (S), U$1.10 (GND), U$1.19 (_OE), U$2.10 (GND), U$2.19 (_OE), U$3.10 (GND), U$3.19 (_OE), U$4.2 (A0), U$4.3 (A1), U$4.4 (A2), U$4.5 (A3), U$4.10 (GND), U$4.15 (B3), U$4.16 (B2), U$4.17 (B1), U$4.18 (B0), U$4.19 (_OE), U$5.3 (ANAIN1), U$5.4 (REFGND), U$5.42 (GND5), U$5.53 (GND4), U$5.63 (GND12), U$5.68 (GND3), U$5.83 (GND2), U$5.95 (GND1), U$5.104 (GND11), U$5.116 (GND10), U$5.125 (GND9), U$5.133 (GND8), U$5.137 (GND7), U$5.142 (GND6), U$5.E (GND_PAD), U$6.3 (VSS1), U$6.6 (VSS2), U$6.GP (GND), U$7.6 (!CE1), U$7.12 (VSS), U$7.34 (VSS), U$8.2 (GND)
JTAGEN: JP1.8, R5.2, U$5.15 (JTAGEN)
unnamed: CART1.1 (!S4), U$1.11 (B7)
unnamed: CART1.A (RD4), U$1.12 (B6)
unnamed: CART1.2 (A3), U$1.13 (B5)
unnamed: CART1.3 (A2), U$1.14 (B4)
unnamed: CART1.C (A4), U$1.15 (B3)
unnamed: CART1.4 (A1), U$1.16 (B2)
unnamed: CART1.D (A5), U$1.17 (B1)
unnamed: CART1.5 (A0), U$1.18 (B0)
unnamed: CART1.E (A6), U$2.11 (B7)
unnamed: CART1.6 (D4), U$2.12 (B6)
unnamed: CART1.F (A7), U$2.13 (B5)
unnamed: CART1.7 (D5), U$2.14 (B4)
unnamed: CART1.H (A8), U$2.15 (B3)
unnamed: CART1.8 (D2), U$2.16 (B2)
unnamed: CART1.J (A9), U$2.17 (B1)
unnamed: CART1.9 (D1), U$2.18 (B0)
unnamed: CART1.K (A12), U$3.11 (B7)
unnamed: CART1.10 (D0), U$3.12 (B6)
unnamed: CART1.L (D3), U$3.13 (B5)
unnamed: CART1.11 (D6), U$3.14 (B4)
unnamed: CART1.M (D7), U$3.15 (B3)
unnamed: CART1.12 (!S5), U$3.16 (B2)
unnamed: CART1.N (A11), U$3.17 (B1)
unnamed: CART1.P (A10), U$3.18 (B0)
unnamed: CART1.14 (RD5), U$4.11 (B7)
unnamed: CART1.R (R/!W), U$4.12 (B6)
unnamed: CART1.15 (!CCTL), U$4.13 (B5)
unnamed: CART1.S (PHI2), U$4.14 (B4)
unnamed: U$5.27 (CLK0P), U$8.3 (OUT)
unnamed: R6.2, U$5.126 (CONFIG_SEL)
unnamed: R7.2, U$5.138 (CONF_DONE)
unnamed: R8.2, U$5.136 (NSTATUS)
unnamed: R9.2, S1.1, U$5.129 (NCONFIG)
unnamed: LED1.A, R10.1
unnamed: LED1.C, U$5.120 (IO8_120)
SD_CLK: U$5.69 (IO4_69), U$6.5 (SCLK)
SD_CS: U$5.65 (IO4_65), U$6.1 (CS)
SD_DI: U$5.66 (IO4_66), U$6.2 (DATA_IN)
SD_DO: R11.2, U$5.70 (IO4_70), U$6.7 (DATA_OUT)
TCK: JP1.1, R2.1, U$5.18 (TCK)
TDI: JP1.9, R4.2, U$5.19 (TDI)
TDO: JP1.3, U$5.20 (TDO)
TMS: JP1.5, R3.2, U$5.16 (TMS)

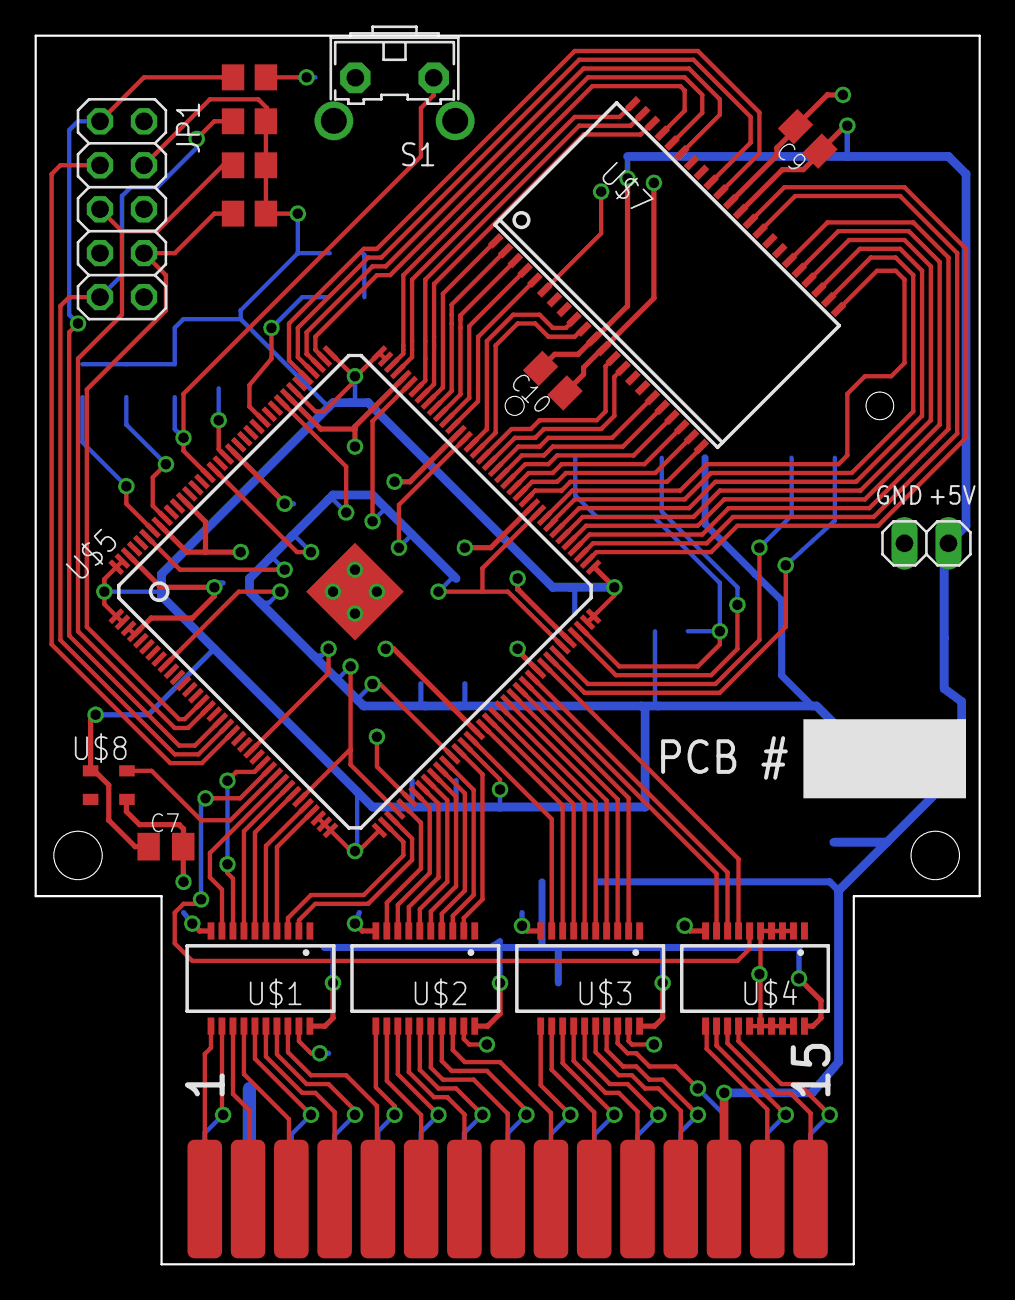
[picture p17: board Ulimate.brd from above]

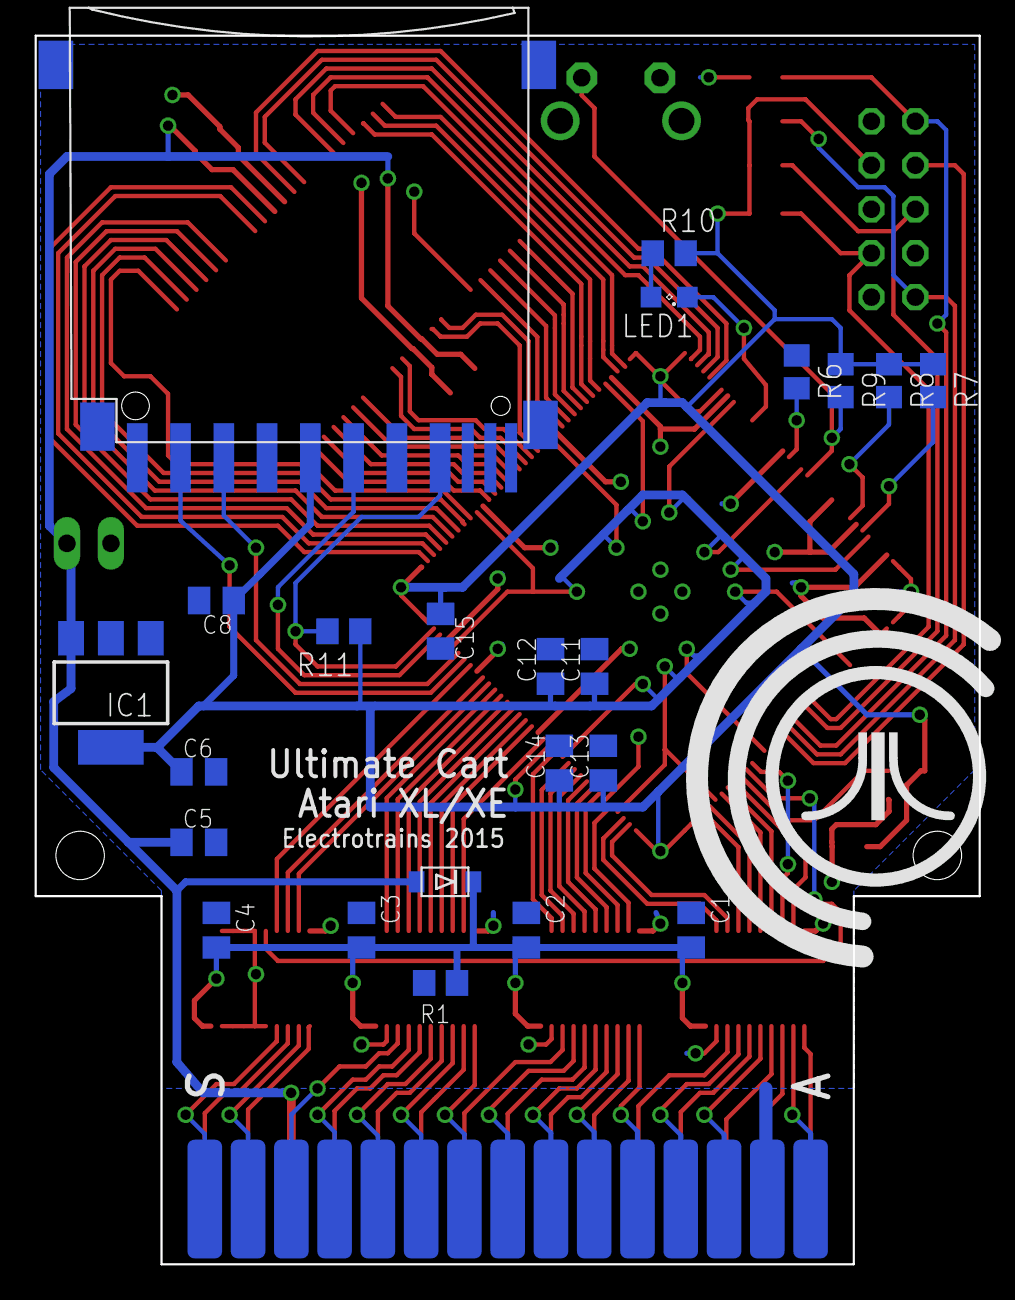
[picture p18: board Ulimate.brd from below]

Board: 2 copper layers, 54.5 x 71.0 mm, 41 parts (23 on the bottom side), 107 nets.

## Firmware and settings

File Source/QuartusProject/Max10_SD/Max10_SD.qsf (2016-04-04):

# -------------------------------------------------------------------------- #
#
# Copyright (C) 1991-2014 Altera Corporation. All rights reserved.
# Your use of Altera Corporation's design tools, logic functions 
# and other software and tools, and its AMPP partner logic 
# functions, and any output files from any of the foregoing 
# (including device programming or simulation files), and any 
# associated documentation or information are expressly subject 
# to the terms and conditions of the Altera Program License 
# Subscription Agreement, the Altera Quartus II License Agreement,
# the Altera MegaCore Function License Agreement, or other 
# applicable license agreement, including, without limitation, 
# that your use is for the sole purpose of programming logic 
# devices manufactured by Altera and sold by Altera or its 
# authorized distributors.  Please refer to the applicable 
# agreement for further details.
#
# -------------------------------------------------------------------------- #
#
# Quartus II 64-Bit
# Version 14.1.0 Build 186 12/03/2014 SJ Web Edition
# Date created = 16:37:56  April 24, 2015
#
# -------------------------------------------------------------------------- #
#
# Notes:
#
# 1) The default values for assignments are stored in the file:
#		Max10_SD_assignment_defaults.qdf
#    If this file doesn't exist, see file:
#		assignment_defaults.qdf
#
# 2) Altera recommends that you do not modify this file. This
#    file is updated automatically by the Quartus II software
#    and any changes you make may be lost or overwritten.
#
# -------------------------------------------------------------------------- #


set_global_assignment -name FAMILY "MAX 10"
set_global_assignment -name DEVICE 10M08SAE144C8G
set_global_assignment -name TOP_LEVEL_ENTITY atari_rom
set_global_assignment -name ORIGINAL_QUARTUS_VERSION 14.1.0
set_global_assignment -name PROJECT_CREATION_TIME_DATE "16:37:56  APRIL 24, 2015"
set_global_assignment -name LAST_QUARTUS_VERSION 15.1.0
set_global_assignment -name PROJECT_OUTPUT_DIRECTORY output_files
set_global_assignment -name MIN_CORE_JUNCTION_TEMP 0
set_global_assignment -name MAX_CORE_JUNCTION_TEMP 85
set_global_assignment -name ERROR_CHECK_FREQUENCY_DIVISOR 2
set_global_assignment -name EDA_SIMULATION_TOOL "ModelSim-Altera (VHDL)"
set_global_assignment -name EDA_OUTPUT_DATA_FORMAT VHDL -section_id eda_simulation
set_global_assignment -name ENABLE_OCT_DONE ON
set_global_assignment -name USE_CONFIGURATION_DEVICE OFF
set_global_assignment -name INTERNAL_FLASH_UPDATE_MODE "SINGLE IMAGE WITH ERAM"
set_global_assignment -name CRC_ERROR_OPEN_DRAIN OFF
set_global_assignment -name OUTPUT_IO_TIMING_NEAR_END_VMEAS "HALF VCCIO" -rise
set_global_assignment -name OUTPUT_IO_TIMING_NEAR_END_VMEAS "HALF VCCIO" -fall
set_global_assignment -name OUTPUT_IO_TIMING_FAR_END_VMEAS "HALF SIGNAL SWING" -rise
set_global_assignment -name OUTPUT_IO_TIMING_FAR_END_VMEAS "HALF SIGNAL SWING" -fall
set_global_assignment -name STRATIX_DEVICE_IO_STANDARD "2.5 V"
set_global_assignment -name QIP_FILE software/sdcard/mem_init/meminit.qip
set_global_assignment -name QIP_FILE host/synthesis/host.qip
set_global_assignment -name VHDL_FILE atari_rom.vhd
set_global_assignment -name PARTITION_NETLIST_TYPE SOURCE -section_id Top
set_global_assignment -name PARTITION_FITTER_PRESERVATION_LEVEL PLACEMENT_AND_ROUTING -section_id Top
set_global_assignment -name PARTITION_COLOR 16764057 -section_id Top
set_location_assignment PIN_27 -to CLK
set_location_assignment PIN_120 -to LED[0]
set_location_assignment PIN_61 -to CART_RD5
set_location_assignment PIN_58 -to CART_S5
set_location_assignment PIN_25 -to CART_RD4
set_location_assignment PIN_28 -to CART_S4
set_location_assignment PIN_39 -to CART_ADDR[0]
set_location_assignment PIN_33 -to CART_ADDR[1]
set_location_assignment PIN_30 -to CART_ADDR[2]
set_location_assignment PIN_29 -to CART_ADDR[3]
set_location_assignment PIN_32 -to CART_ADDR[4]
set_location_assignment PIN_38 -to CART_ADDR[5]
set_location_assignment PIN_41 -to CART_ADDR[6]
set_location_assignment PIN_44 -to CART_ADDR[7]
set_location_assignment PIN_46 -to CART_ADDR[8]
set_location_assignment PIN_48 -to CART_ADDR[9]
set_location_assignment PIN_60 -to CART_ADDR[10]
set_location_assignment PIN_59 -to CART_ADDR[11]
set_location_assignment PIN_52 -to CART_ADDR[12]
set_instance_assignment -name IO_STANDARD "3.3-V LVTTL" -to SD_CARD_cs
set_instance_assignment -name IO_STANDARD "3.3-V LVTTL" -to SD_CARD_miso
set_instance_assignment -name IO_STANDARD "3.3-V LVTTL" -to SD_CARD_mosi
set_instance_assignment -name IO_STANDARD "3.3-V LVTTL" -to SD_CARD_sclk
set_instance_assignment -name IO_STANDARD "3.3-V LVTTL" -to CART_RD5
set_instance_assignment -name IO_STANDARD "3.3-V LVTTL" -to CART_S5
set_instance_assignment -name IO_STANDARD "3.3-V LVTTL" -to CART_RD4
set_instance_assignment -name IO_STANDARD "3.3-V LVTTL" -to CART_S4
set_instance_assignment -name IO_STANDARD "3.3-V LVTTL" -to CART_ADDR[12]
set_instance_assignment -name IO_STANDARD "3.3-V LVTTL" -to CART_ADDR[11]
set_instance_assignment -name IO_STANDARD "3.3-V LVTTL" -to CART_ADDR[10]
set_instance_assignment -name IO_STANDARD "3.3-V LVTTL" -to CART_ADDR[9]
set_instance_assignment -name IO_STANDARD "3.3-V LVTTL" -to CART_ADDR[8]
set_instance_assignment -name IO_STANDARD "3.3-V LVTTL" -to CART_ADDR[7]
set_instance_assignment -name IO_STANDARD "3.3-V LVTTL" -to CART_ADDR[6]
set_instance_assignment -name IO_STANDARD "3.3-V LVTTL" -to CART_ADDR[5]
set_instance_assignment -name IO_STANDARD "3.3-V LVTTL" -to CART_ADDR[4]
set_instance_assignment -name IO_STANDARD "3.3-V LVTTL" -to CART_ADDR[3]
set_instance_assignment -name IO_STANDARD "3.3-V LVTTL" -to CART_ADDR[2]
set_instance_assignment -name IO_STANDARD "3.3-V LVTTL" -to CART_ADDR[1]
set_instance_assignment -name IO_STANDARD "3.3-V LVTTL" -to CART_ADDR[0]
set_instance_assignment -name IO_STANDARD "3.3-V LVTTL" -to CART_DATA[7]
set_instance_assignment -name IO_STANDARD "3.3-V LVTTL" -to CART_DATA[6]
set_instance_assignment -name IO_STANDARD "3.3-V LVTTL" -to CART_DATA[5]
set_instance_assignment -name IO_STANDARD "3.3-V LVTTL" -to CART_DATA[4]
set_instance_assignment -name IO_STANDARD "3.3-V LVTTL" -to CART_DATA[3]
set_instance_assignment -name IO_STANDARD "3.3-V LVTTL" -to CART_DATA[2]
set_instance_assignment -name IO_STANDARD "3.3-V LVTTL" -to CART_DATA[1]
set_instance_assignment -name IO_STANDARD "3.3-V LVTTL" -to CART_DATA[0]
set_instance_assignment -name IO_STANDARD "3.3-V LVTTL" -to CLK
set_instance_assignment -name IO_STANDARD "3.3-V LVTTL" -to LED[0]
set_location_assignment PIN_54 -to CART_DATA[0]
set_location_assignment PIN_50 -to CART_DATA[1]
set_location_assignment PIN_47 -to CART_DATA[2]
set_location_assignment PIN_55 -to CART_DATA[3]
set_location_assignment PIN_57 -to CART_DATA[7]
set_location_assignment PIN_56 -to CART_DATA[6]
set_location_assignment PIN_45 -to CART_DATA[5]
set_location_assignment PIN_43 -to CART_DATA[4]
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

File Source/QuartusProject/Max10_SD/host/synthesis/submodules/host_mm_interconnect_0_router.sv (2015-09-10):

// (C) 2001-2015 Altera Corporation. All rights reserved.
// Your use of Altera Corporation's design tools, logic functions and other 
// software and tools, and its AMPP partner logic functions, and any output 
// files any of the foregoing (including device programming or simulation 
// files), and any associated documentation or information are expressly subject 
// to the terms and conditions of the Altera Program License Subscription 
// Agreement, Altera MegaCore Function License Agreement, or other applicable 
// license agreement, including, without limitation, that your use is for the 
// sole purpose of programming logic devices manufactured by Altera and sold by 
// Altera or its authorized distributors.  Please refer to the applicable 
// agreement for further details.



// Your use of Altera Corporation's design tools, logic functions and other 
// software and tools, and its AMPP partner logic functions, and any output 
// files any of the foregoing (including device programming or simulation 
// files), and any associated documentation or information are expressly subject 
// to the terms and conditions of the Altera Program License Subscription 
// Agreement, Altera MegaCore Function License Agreement, or other applicable 
// license agreement, including, without limitation, that your use is for the 
// sole purpose of programming logic devices manufactured by Altera and sold by 
// Altera or its authorized distributors.  Please refer to the applicable 
// agreement for further details.


// $Id: //acds/rel/14.1/ip/merlin/altera_merlin_router/altera_merlin_router.sv.terp#1 $
// $Revision: #1 $
// $Date: 2014/10/06 $
// $Author: swbranch $

// -------------------------------------------------------
// Merlin Router
//
// Asserts the appropriate one-hot encoded channel based on 
// either (a) the address or (b) the dest id. The DECODER_TYPE
// parameter controls this behaviour. 0 means address decoder,
// 1 means dest id decoder.
//
// In the case of (a), it also sets the destination id.
// -------------------------------------------------------

`timescale 1 ns / 1 ns

module host_mm_interconnect_0_router_default_decode
  #(
     parameter DEFAULT_CHANNEL = 1,
               DEFAULT_WR_CHANNEL = -1,
               DEFAULT_RD_CHANNEL = -1,
               DEFAULT_DESTID = 3 
   )
  (output [86 - 83 : 0] default_destination_id,
   output [12-1 : 0] default_wr_channel,
   output [12-1 : 0] default_rd_channel,
   output [12-1 : 0] default_src_channel
  );

  assign default_destination_id = 
    DEFAULT_DESTID[86 - 83 : 0];

  generate
    if (DEFAULT_CHANNEL == -1) begin : no_default_channel_assignment
      assign default_src_channel = '0;
    end
    else begin : default_channel_assignment
      assign default_src_channel = 12'b1 << DEFAULT_CHANNEL;
    end
  endgenerate

  generate
    if (DEFAULT_RD_CHANNEL == -1) begin : no_default_rw_channel_assignment
      assign default_wr_channel = '0;
      assign default_rd_channel = '0;
    end
    else begin : default_rw_channel_assignment
      assign default_wr_channel = 12'b1 << DEFAULT_WR_CHANNEL;
      assign default_rd_channel = 12'b1 << DEFAULT_RD_CHANNEL;
    end
  endgenerate

endmodule


module host_mm_interconnect_0_router
(
    // -------------------
    // Clock & Reset
    // -------------------
    input clk,
    input reset,

    // -------------------
    // Command Sink (Input)
    // -------------------
    input                       sink_valid,
    input  [100-1 : 0]    sink_data,
    input                       sink_startofpacket,
    input                       sink_endofpacket,
    output                      sink_ready,

    // -------------------
    // Command Source (Output)
    // -------------------
    output                          src_valid,
    output reg [100-1    : 0] src_data,
    output reg [12-1 : 0] src_channel,
    output                          src_startofpacket,
    output                          src_endofpacket,
    input                           src_ready
);

    // -------------------------------------------------------
    // Local parameters and variables
    // -------------------------------------------------------
    localparam PKT_ADDR_H = 57;
    localparam PKT_ADDR_L = 36;
    localparam PKT_DEST_ID_H = 86;
    localparam PKT_DEST_ID_L = 83;
    localparam PKT_PROTECTION_H = 90;
    localparam PKT_PROTECTION_L = 88;
    localparam ST_DATA_W = 100;
    localparam ST_CHANNEL_W = 12;
    localparam DECODER_TYPE = 0;

    localparam PKT_TRANS_WRITE = 60;
    localparam PKT_TRANS_READ  = 61;

    localparam PKT_ADDR_W = PKT_ADDR_H-PKT_ADDR_L + 1;
    localparam PKT_DEST_ID_W = PKT_DEST_ID_H-PKT_DEST_ID_L + 1;



    // -------------------------------------------------------
    // Figure out the number of bits to mask off for each slave span
    // during address decoding
    // -------------------------------------------------------
    localparam PAD0 = log2ceil(64'h200000 - 64'h100000); 
    localparam PAD1 = log2ceil(64'h210000 - 64'h208000); 
    localparam PAD2 = log2ceil(64'h214000 - 64'h212000); 
    localparam PAD3 = log2ceil(64'h215000 - 64'h214800); 
    localparam PAD4 = log2ceil(64'h215020 - 64'h215000); 
    localparam PAD5 = log2ceil(64'h215040 - 64'h215020); 
    localparam PAD6 = log2ceil(64'h215050 - 64'h215040); 
    localparam PAD7 = log2ceil(64'h215060 - 64'h215050); 
    localparam PAD8 = log2ceil(64'h215070 - 64'h215060); 
    localparam PAD9 = log2ceil(64'h215080 - 64'h215070); 
    localparam PAD10 = log2ceil(64'h215088 - 64'h215080); 
    localparam PAD11 = log2ceil(64'h215090 - 64'h215088); 
    // -------------------------------------------------------
    // Work out which address bits are significant based on the
    // address range of the slaves. If the required width is too
    // large or too small, we use the address field width instead.
    // -------------------------------------------------------
    localparam ADDR_RANGE = 64'h215090;
    localparam RANGE_ADDR_WIDTH = log2ceil(ADDR_RANGE);
    localparam OPTIMIZED_ADDR_H = (RANGE_ADDR_WIDTH > PKT_ADDR_W) ||
                                  (RANGE_ADDR_WIDTH == 0) ?
                                        PKT_ADDR_H :
                                        PKT_ADDR_L + RANGE_ADDR_WIDTH - 1;

    localparam RG = RANGE_ADDR_WIDTH-1;
    localparam REAL_ADDRESS_RANGE = OPTIMIZED_ADDR_H - PKT_ADDR_L;

      reg [PKT_ADDR_W-1 : 0] address;
      always @* begin
        address = {PKT_ADDR_W{1'b0}};
        address [REAL_ADDRESS_RANGE:0] = sink_data[OPTIMIZED_ADDR_H : PKT_ADDR_L];
      end
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

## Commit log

2015-08-17 initial commit of board files
    [Ulimate.brd, Ulimate.sch]
2015-08-17 add BOM
2015-08-17 fix BOM
2015-09-22 update pcb
    [Ulimate.brd, Ulimate.sch]
2015-09-27 add assembly instructions
2015-10-08 updates to BOM
2015-10-30 fixes signal integrity issues on XL machines
    [Boot.asm, Max10_SD.qsf]
2016-03-01 add v3 board with 47k resistor
    [Ulimate.brd, Ulimate.sch]
2017-07-13 add STL files for shell
    [ultimate_back.scad, ultimate_back.stl, ultimate_front.scad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]
2023-04-26 New firmware (#5)
    * Update avr-objcopy.exe
    version is updated, it does not need external DLLs to run. GNU objcopy (GNU Binutils) 2.36.1
    * Update atari_rom.vhd
    Fix for Atari 800 S4 & S5 are always active. Only the RAM is not mapped when RD4, RD5 is driven high
    * TURBOSOFT cartridge
    Support for TURBOSOFT 64k and 128k cartridges.
    * ATRAX cartridge
    Support for Atrax 128K cartridges.
    * Patch for DLI
    DLI flicker fixed
    Contribution from flashjazzcat
    * Patch for .XEX
    BOOT? set to 1
    CRITIC asserted during segment reads
    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
    [Boot.asm]

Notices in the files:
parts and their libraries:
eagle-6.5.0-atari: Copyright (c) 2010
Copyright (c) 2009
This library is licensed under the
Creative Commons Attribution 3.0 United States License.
